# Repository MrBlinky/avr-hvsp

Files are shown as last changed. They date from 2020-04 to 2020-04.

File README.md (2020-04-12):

# avr-hvsp
High voltage serial programmer for AVR Attiny devices

* Easy to make programmer using 12V DC-DC converter with enable and ATMEGA32U4 Beetle board.
* Programs AVR Attiny devices in high voltage mode to recover fuse settings and allow reset pin to be used as GPIO pin.
* Works with Arduino IDE / AVRdude.
* No hassle with Windows driver utilities. Uses built in windows 10 driver or Arduino IDE driver.

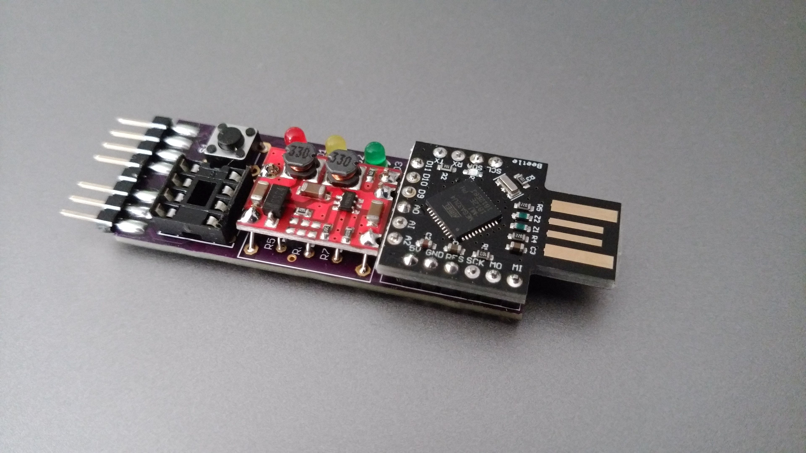
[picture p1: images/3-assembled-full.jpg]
fully assembled image


## Parts

|Qty. | Discription |
| --- | --- |
| 1 | 12V DC-DC converter/booster module with enable |
| 1 | ATMEGA32U4 Beetle board without parts on PCB bottom + headers (No 3.3V pin and no extra GND pins on top row.) |
| 1 | 3 mm Red LED |
| 1 | 3 mm Yellow LED |
| 1 | 3 mm Green LED |
| 5 | 470 Ohm resistor  (1/8 Watt) |
| 2 | 1K resistor (1/8 Watt) |
| 1 | PM48XP P-channel MOSFET SOT23 package (optional)* |
| 1 | 8 pin header (for programming connector) |
| 1 | 2 pin header (for DC-DC converter) |
| 3 | 1 pin header (for DC-DC converter) |
| 1 | 8 pin IC socket |
| 1 | 6x6mm tactile button |
 
*A MOSFET is recommended for a more powerful VCC. However if devices are
 only programmed using the IC socket or in low power circuits (<20mA),
 the MOSFET can be left out. In that case VCC is powered by a GPIO pin
 by shorting jumper J1. When using a MOSFET, Jumper J1 must be left open.

Revision 1.1 PCB can be ordered through [OSH Park](https://oshpark.com/shared_projects/vXxMrB8z)

## Assembly

Assemble parts with low height first (programming header, MOSFET at bottom, resistors IC socket, button, LEDs and modules as last).
Check a parts aligment after soldering the first pin and when it's aligned properly solder remaining pins.

Before soldering the module headers, place headers with long end into main PCB and mount modules on top for easy aligment. Solder one pin of each header at top of module and check if headers are straight then solder remaining pins at top of the modules. Cut excess length of header pins at bottom of the main PCB and then solder them.

## upload programmer firmware

* Open **hvsp.ino** sketch by double clicking or open file with Arduino IDE
* Select **Arduino Leonardo** board from **Tools** menu.
* Select **port** from **Tools** menu.
* Upload sketch

## Programming a device

Insert 8-pin DIP devices in to socket or wire-up device to programming header (check device datasheet for wiring).
Upload a sketch using Arduino IDE or upload a hex file directly using AVRdude.

LED status:
* Red LED on: 12V VPP programming voltage on. Red LED off: Programming voltage off.
* Yellow LED on: 5V VCC on. Yellow LED off: 5V VCC off.
* Green LED on: Both programming and VCC are off. Green LED off: VPP and/or VCC on.

Button control:

Short press (< 500 ms): Toggle VCC on/off.
long press (>= 500 ms): TO DO

### using Arduino IDE

select **Arduino as ISP (ATmega32U4)** as **programmer** from **Tools** menu

### using AVRdude

Use **-carduino** as programmer switch and specify serial port with *-P* switch

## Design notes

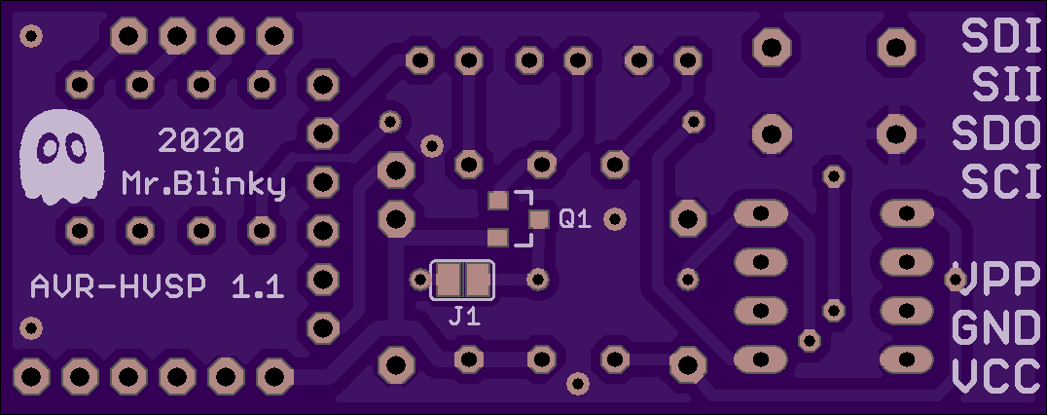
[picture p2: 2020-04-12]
images/rev1.1-bottom.png

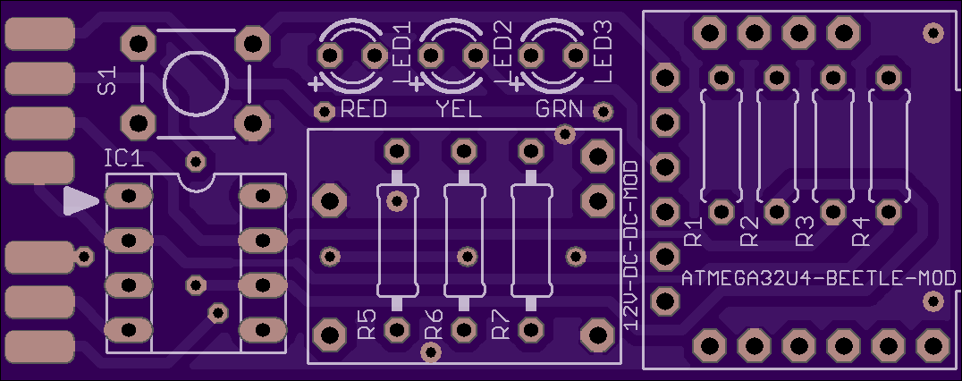
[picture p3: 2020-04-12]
images/rev1.1-top.png

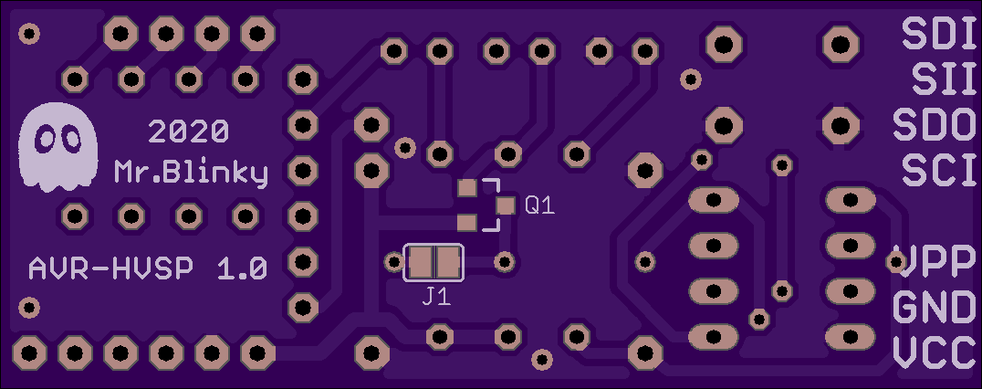
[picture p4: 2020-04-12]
images/rev1.0-bottom.png

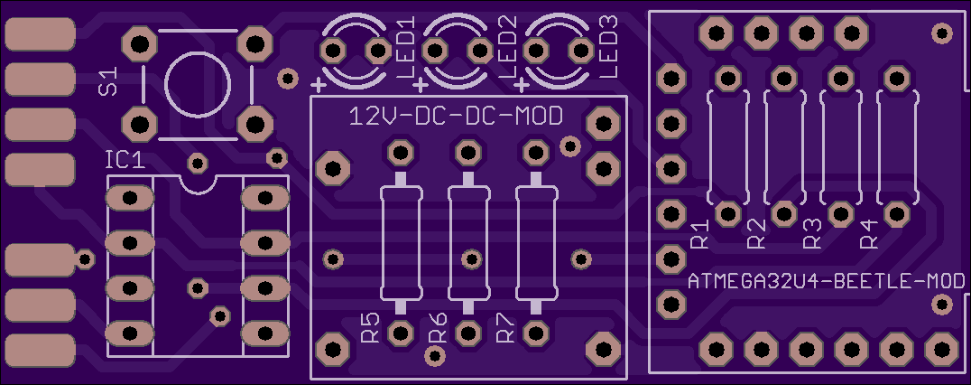
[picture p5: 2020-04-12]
images/rev1.0-top.png

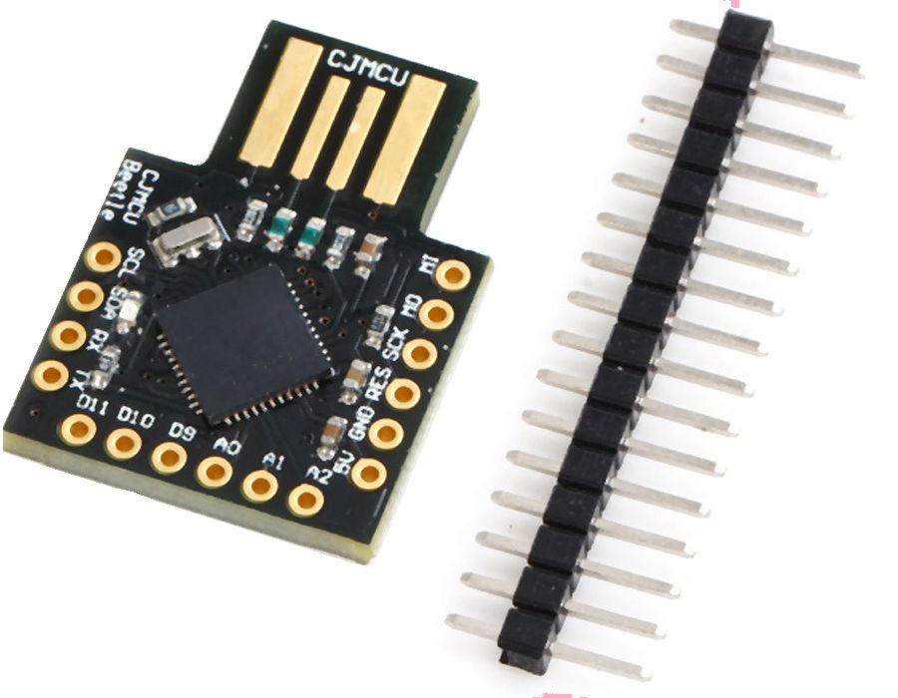
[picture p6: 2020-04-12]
images/beetle-board-without-3v3.jpg

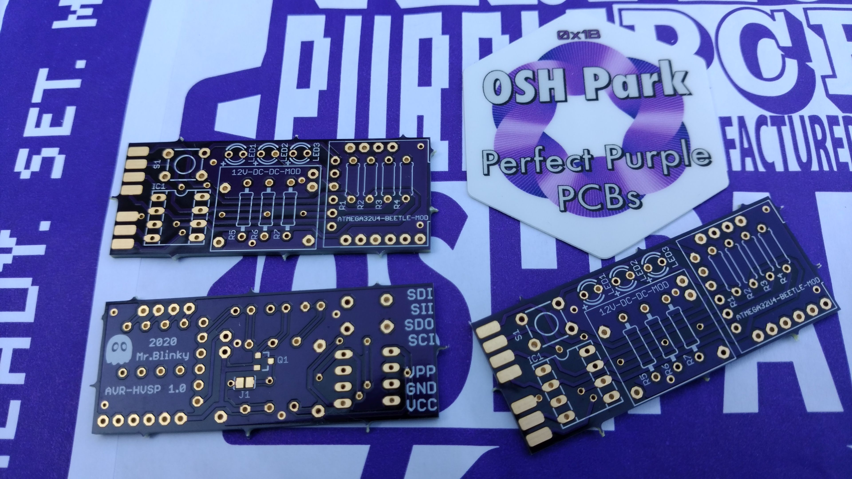
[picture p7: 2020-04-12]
images/1-oshpark-pcb.jpg

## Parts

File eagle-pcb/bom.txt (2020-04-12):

 1x 12V DC-DC converter/booster module with enable
 1x ATMEGA32U4 Beetle board without parts on PCB bottom + headers
    (No 3.3V pin and no extra GND pins on top row.)
 1x 3 mm Red LED
 1x 3 mm Yellow LED
 1x 3 mm Green LED
 5x 470 Ohm resistor  (1/8 Watt)
 2x 1K resistor (1/8 Watt)
 1x PM48XP P-channel MOSFET SOT23 package (optional)*
 1x 8 pin header (for programming connector)
 1x 2 pin header (for DC-DC converter)
 3x 1 pin header (for DC-DC converter)
 1x 8 pin IC socket
 1x 6x6mm tactile button
 
*A MOSFET is recommended for a more powerful VCC. However if devices are only
 programmed using the IC socket or in low power circuits (<20mA), the MOSFET 
 can be left out. In that case VCC is powered by a GPIO pin by shorting
 jumper J1. When using a MOSFET, Jumper J1 must be left open.

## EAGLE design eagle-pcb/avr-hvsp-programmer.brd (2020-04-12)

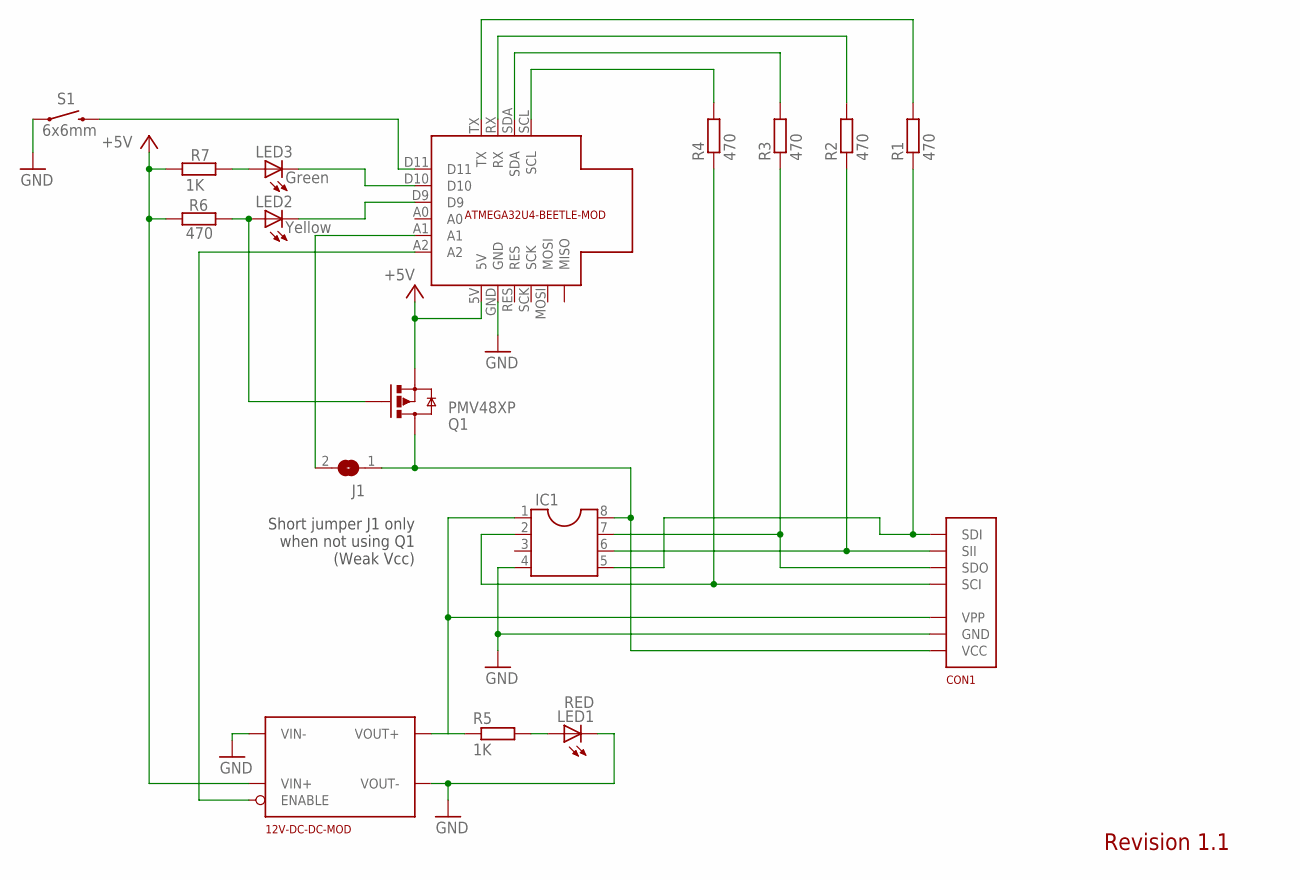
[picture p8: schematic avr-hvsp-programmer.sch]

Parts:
12V-DC-DC-MOD: 12V-DC-DC-CONVERTER-WITH_ENABLE; 12V-DC-DC-CONVERTER-WITH-ENABLE
ATMEGA32U4-BEETLE-MOD: ATMEGA32U4-BEETLE-BOARD
CON1: HVSP-HEADER
IC1: DIL8S; SOCKET-08
J1: SJ
LED1: RED; LED3MM
LED2: Yellow; LED3MM
LED3: Green; LED3MM
Q1: PMV48XP; SOT23-3
R1, R2, R3, R4: 470; 0207/7
R5, R7: 1K; 0207/10
R6: 470; 0207/10
S1: 6x6mm; TACTILE_SWITCH_PTH_6.0MM

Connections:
+5V: 12V-DC-DC-MOD.VIN+, ATMEGA32U4-BEETLE-MOD.5V, Q1.2 (S), R6.1, R7.1
GND: 12V-DC-DC-MOD.VIN-, 12V-DC-DC-MOD.VOUT-, ATMEGA32U4-BEETLE-MOD.GND, CON1.GND, IC1.4, LED1.K (C), S1.1
LED2: ATMEGA32U4-BEETLE-MOD.D9, LED2.K (C)
LED3: ATMEGA32U4-BEETLE-MOD.D10, LED3.K (C)
unnamed: ATMEGA32U4-BEETLE-MOD.TX, R1.2
unnamed: ATMEGA32U4-BEETLE-MOD.RX, R2.2
unnamed: ATMEGA32U4-BEETLE-MOD.SDA, R3.2
unnamed: ATMEGA32U4-BEETLE-MOD.SCL, R4.2
R-LED1: LED1.A, R5.2
R-LED2: LED2.A, Q1.1 (G), R6.2
R-LED3: LED3.A, R7.2
S1: ATMEGA32U4-BEETLE-MOD.D11, S1.3 (2)
SCI: CON1.SCI, IC1.2, R4.1
SDI: CON1.SDI, IC1.5, R1.1
SDO: CON1.SDO, IC1.7, R3.1
SII: CON1.SII, IC1.6, R2.1
VCC: CON1.VCC, IC1.8, J1.1, Q1.3 (D)
VCC_WEAK: ATMEGA32U4-BEETLE-MOD.A1, J1.2
VPP: 12V-DC-DC-MOD.VOUT+, CON1.VPP, IC1.1, R5.1
VPP_ENABLE: 12V-DC-DC-MOD.ENABLE, ATMEGA32U4-BEETLE-MOD.A2

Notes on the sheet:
Short jumper J1 only when not using Q1 (Weak Vcc)
Revision 1.1

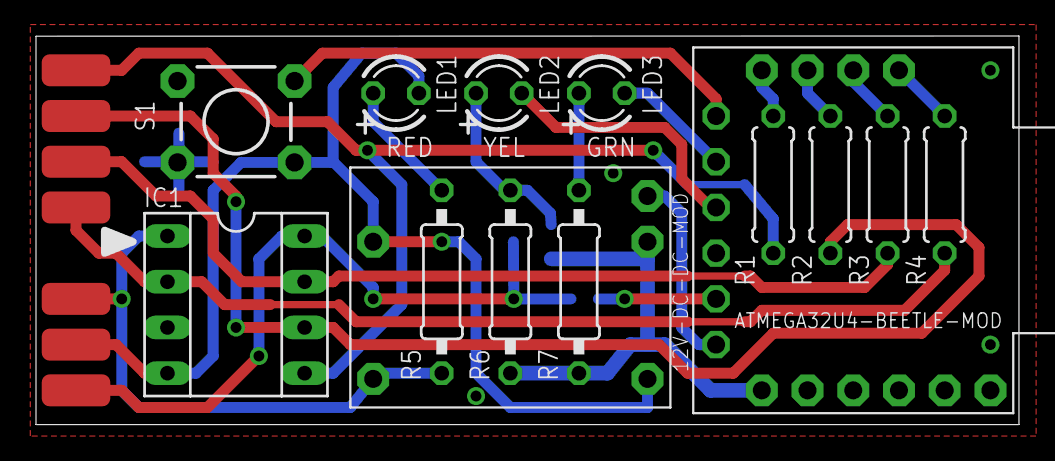
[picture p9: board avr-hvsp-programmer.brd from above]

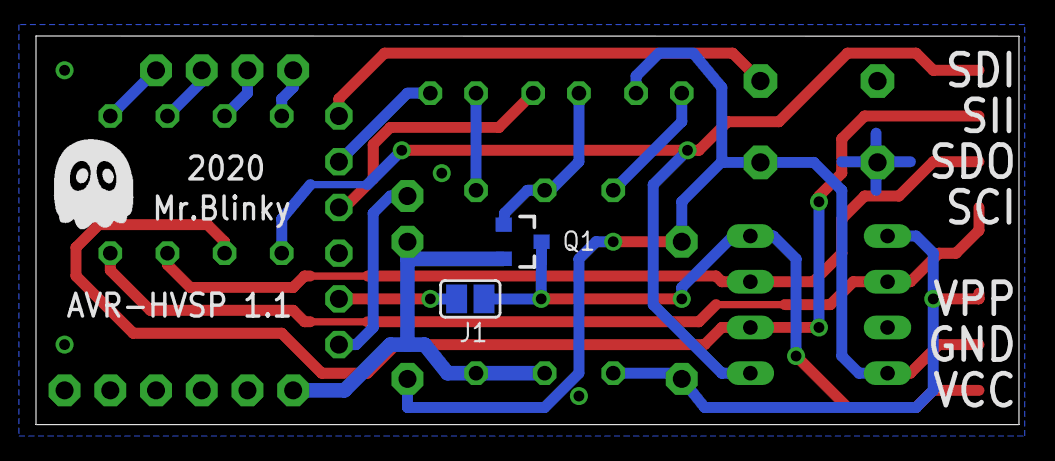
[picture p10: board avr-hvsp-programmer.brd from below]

Board: 2 copper layers, 54.6 x 21.6 mm, 17 parts (2 on the bottom side), 20 nets.

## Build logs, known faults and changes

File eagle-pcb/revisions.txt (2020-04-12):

1.0 First release. Minior issue: DC-DC converter module is 0.1"too wide

1.1 reduced DC-DC converter module width by 0.1"
    adjusted routing due to narrower DC-DC converter module
    increased DC-DC converter module drill size from 0.9mm to 1.0mm
    increased beetle module drill size from 0.9mm to 1.0mm
    changed revision text from 1.0 to 1.1
    
    Schematic changes:    
    changed value red LED resistor R5 to 1K
    changed value yellow LED resistor R6 to 470
    changed value green LED resistor R7 to 1K

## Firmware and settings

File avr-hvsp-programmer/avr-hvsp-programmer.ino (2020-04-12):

/******************************************************************************/
// AVR High Voltage Serial Programmer 1.01 by Mr.Blinky Mar-Apr.2020 CC0 Licence
/******************************************************************************

Atmega32u4 beetle board wiring
------------------------------
 
       SCI __________
       SDO ________  |
       SII ______  | |
       SDI ____  | | |
             __|_|_|_|_______
            |  O O O O       |
BUTTON     _|O               |____
LED_GREEN  _|O        LED         |_BUILTIN_LED
VCC_LED    _|O                    |
           _|O                    |
WEAK_VCC   _|O                ____|
VPP        _|O               |
            |__O_O_O_O_O_O_O_|
        5V ____| |
       GND ______|

connect SCI,SDO,SII and SDI to device with 470 Ohm resistors in series.

connect BUTTON to momentary pushbutton and other end of button to GND

connect cathode(-) of green LED to LED_GREEN pin
connect 330 Ohm resistor to anode(+) of green LED pin
connect other end 330 Ohm resistor to 5V

connect cathode(-) of yellow LED to VCC_LED pin
connect 330 Ohm resistor to anode(+) of yellow LED pin 
connect other end 330 Ohm resistor to 5V

for low power device/circuit:
-----------------------------
Connect WEAK_VCC directly to device VCC pin.

for more demanding circuits:
----------------------------
leave WEAK_VCC unconnected and connect a P-channel MOSFET as following:
Connect MOSFET Source to 5V, Connect MOSFET Drain to device VCC and 
connect MOSFET Gate to anode(+) of yellow LED.

Connect VPP to enable input of 12V DC-DC converter module

connect 1K resistor to 12V
connect other end of 1K resistor to anode(+) of the red LED
connect cathode(-) of the red LED to GND

*******************************************************************************/

// version info
constexpr uint8_t HARDWAREVERSION       = 2;
// 1: for basic prototype made of beetle board, 12V DC-DC converter module and weak vcc
// 2: PCB version with added Vcc LED, Green LED and feature button
//    (P-channel MOSFET for more powerfull VCC is optional)

constexpr uint8_t SOFTWAREVERSION_MAJOR = 1;
constexpr uint8_t SOFTWAREVERSION_MINOR = 1;

// pin configurations (Using direct IO instead of slow DigitalRead/Write and pinMode)

#define HVSP_SCI_BIT    0       // 3/SCL output connected to SCI pin
#define HVSP_SCI_PIN    PIND
#define HVSP_SCI_PORT   PORTD
#define HVSP_SCI_DDR    DDRD

#define HVSP_SDO_BIT    1       // 2/SDA input/output connected to Serial Data Output (SDO) pin
#define HVSP_SDO_PIN    PIND
#define HVSP_SDO_PORT   PORTD
#define HVSP_SDO_DDR    DDRD

#define HVSP_SII_BIT    2       // RX output connect to Serial Instruction Input (SII) pin
#define HVSP_SII_PIN    PIND
#define HVSP_SII_PORT   PORTD
#define HVSP_SII_DDR    DDRD

#define HVSP_SDI_BIT    3       // TX output connected to Serial Data Input (SDI) pin
#define HVSP_SDI_PIN    PIND
#define HVSP_SDI_PORT   PORTD
#define HVSP_SDI_DDR    DDRD
 
#define BUTTON_BIT      7       // D11 Special function button: 
#define BUTTON_PIN      PINB    // short press: toggle VCC state
#define BUTTON_PORT     PORTB   // long press: burn fuse settings and/or embedded hexfile
#define BUTTON_DDR      DDRB

#define GREEN_LED_BIT   6       // D10 active low turns LED on. 
#define GREEN_LED_PIN   PINB    // Status LED to tell both VCC and VPP are disabled
#define GREEN_LED_PORT  PORTB
#define GREEN_LED_DDR   DDRB

#define VCC_LED_BIT     5       // D9 active low turns LED on. 
#define VCC_LED_PIN     PINB    // Status LED to tell VCC_WEAK is enabled.
#define VCC_LED_PORT    PORTB   // when a P-Channel MOSFET is used, it also powers on VCC
#define VCC_LED_DDR     DDRB

#define VCC_BIT         6       // A1 active high turns weak VCC on.
#define VCC_PIN         PINF    // this pin powers VCC directly when no MOSFET is used
#define VCC_PORT        PORTF
#define VCC_DDR         DDRF

#define VPP_BIT         5       // A2 active low turns the 12V DC-DC converter on. 
#define VPP_PIN         PINF    // The RED VPP LED is powered by 12V
#define VPP_PORT        PORTF
#define VPP_DDR         DDRF

#define BUILTIN_LED_BIT  7       // D13 Leonardo/Beetle board built in LED  
#define BUILTIN_LED_PIN  PINC    
#define BUILTIN_LED_PORT PORTC   
#define BUILTIN_LED_DDR  DDRC

// pin configure macros
#define HVSP_SCI_AS_INPUT   (HVSP_SCI_DDR  &= ~(1 << HVSP_SCI_BIT))
#define HVSP_SCI_AS_OUTPUT  (HVSP_SCI_DDR  |=  (1 << HVSP_SCI_BIT))

#define HVSP_SDO_AS_INPUT   (HVSP_SDO_DDR  &= ~(1 << HVSP_SDO_BIT))
#define HVSP_SDO_AS_OUTPUT  (HVSP_SDO_DDR  |=  (1 << HVSP_SDO_BIT))
#define HVSP_SDO_PULLUP_ON  (HVSP_SDO_PORT |=  (1 << HVSP_SDO_BIT))
#define HVSP_SDO_PULLUP_OFF (HVSP_SDO_PORT &= ~(1 << HVSP_SDO_BIT))

#define HVSP_SII_AS_INPUT   (HVSP_SII_DDR  &= ~(1 << HVSP_SII_BIT))
#define HVSP_SII_AS_OUTPUT  (HVSP_SII_DDR  |=  (1 << HVSP_SII_BIT))

#define HVSP_SDI_AS_INPUT   (HVSP_SDI_DDR  &= ~(1 << HVSP_SDI_BIT))
#define HVSP_SDI_AS_OUTPUT  (HVSP_SDI_DDR  |=  (1 << HVSP_SDI_BIT))

#define BUTTON_AS_INPUT     (BUTTON_DDR    &= ~(1 << BUTTON_BIT))
#define BUTTON_PULLUP_ON    (BUTTON_PORT   |=  (1 << BUTTON_BIT))
#define GREEN_LED_AS_OUTPUT (GREEN_LED_DDR |=  (1 << GREEN_LED_BIT))
#define VCC_LED_AS_OUTPUT   (VCC_LED_DDR   |=  (1 << VCC_LED_BIT))

#define VCC_AS_INPUT        (VCC_DDR       &= ~(1 << VCC_BIT))
#define VCC_AS_OUTPUT       (VCC_DDR       |=  (1 << VCC_BIT))
#define VPP_AS_OUTPUT       (VPP_DDR       |= (1 << VPP_BIT))

#define BUILTIN_LED_AS_OUTPUT (BUILTIN_LED_DDR |=  (1 << BUILTIN_LED_BIT))

// pin state macros
#define HVSP_SCI_LOW    (HVSP_SCI_PORT &= ~(1 << HVSP_SCI_BIT))
#define HVSP_SCI_HIGH   (HVSP_SCI_PORT |=  (1 << HVSP_SCI_BIT))
#define HVSP_SDO_LOW    (HVSP_SDO_PORT &= ~(1 << HVSP_SDO_BIT))
#define HVSP_SDO_HIGH   (HVSP_SDO_PORT |=  (1 << HVSP_SDO_BIT))
#define HVSP_SII_LOW    (HVSP_SII_PORT &= ~(1 << HVSP_SII_BIT))
#define HVSP_SII_HIGH   (HVSP_SII_PORT |=  (1 << HVSP_SII_BIT))
#define HVSP_SDI_LOW    (HVSP_SDI_PORT &= ~(1 << HVSP_SDI_BIT)) 
#define HVSP_SDI_HIGH   (HVSP_SDI_PORT |=  (1 << HVSP_SDI_BIT)) 

#define GREEN_LED_OFF   (GREEN_LED_PORT  |=  (1 << GREEN_LED_BIT))
#define GREEN_LED_ON    (GREEN_LED_PORT  &= ~(1 << GREEN_LED_BIT))
#define VCC_LED_OFF     (VCC_LED_PORT    |=  (1 << VCC_LED_BIT))
#define VCC_LED_ON      (VCC_LED_PORT    &= ~(1 << VCC_LED_BIT))
#define VCC_OFF         (VCC_PORT        &= ~(1 << VCC_BIT))
#define VCC_ON          (VCC_PORT        |=  (1 << VCC_BIT))
#define VPP_OFF         (VPP_PORT &= ~(1 << VPP_BIT))
#define VPP_ON          (VPP_PORT |= (1 << VPP_BIT))

#define BUILTIN_LED_OFF (BUILTIN_LED_PORT  &= ~(1 << BUILTIN_LED_BIT))
#define BUILTIN_LED_ON  (BUILTIN_LED_PORT  |=  (1 << BUILTIN_LED_BIT))

// pin input macro
#define HVSP_SDO_STATE  (HVSP_SDO_PIN & (1 << HVSP_SDO_BIT))

// vars
bool progMode;          // programmer state
bool keepVccOn;         // Vcc state after ending programmer mode
uint16_t currAddr;      // current flash/EEPROM word address
uint8_t flashPage;      // flash page of current word address

bool buttonState;
bool buttonStateOld;    
uint16_t oldMillis;
/*******************************************************************************/
// low level hardware functions
/*******************************************************************************/

void vccDown()
{
  VCC_AS_INPUT;
  VCC_OFF;
  VCC_LED_AS_OUTPUT;
  VCC_LED_OFF;
  GREEN_LED_AS_OUTPUT;
  GREEN_LED_ON;
}

void vccUp()
{
  VCC_AS_OUTPUT;
  VCC_ON;
  VCC_LED_AS_OUTPUT;
  VCC_LED_ON;
  GREEN_LED_AS_OUTPUT;
  GREEN_LED_OFF;
}

void HVSP_init()
{
  BUTTON_AS_INPUT;
  BUTTON_PULLUP_ON;
  VPP_AS_OUTPUT;
  VPP_OFF;
  HVSP_disable();
  vccDown();
}

void HVSP_enable()
{
  if (progMode) return; //already in programming mode
  
  if (keepVccOn) // Vcc must be off to successfully enter programming mode
  {
    VPP_ON;      // trigger a device reset to wake possible sleeping devices
    delay(25);
    VPP_OFF;
    delay(25);
    vccDown();
    delay(250);  // wait for Vcc to go down.
  }
  HVSP_SCI_AS_OUTPUT;
  HVSP_SCI_LOW;
  // set Prog_enable pins to '000'
  HVSP_SDO_AS_OUTPUT;
  HVSP_SDO_LOW;
  HVSP_SII_AS_OUTPUT;
  HVSP_SII_LOW;
  HVSP_SDI_AS_OUTPUT;
  HVSP_SDI_LOW;
  // Enter High-voltage Serial programming mode
  vccUp();
  delayMicroseconds(20);
  VPP_ON;
  delayMicroseconds(10);
  // release Prog_enable[2] pin
  HVSP_SDO_AS_INPUT; 
  HVSP_SDO_PULLUP_ON; 
  delayMicroseconds(300);
  progMode = true;
  buttonState = false;
}

void HVSP_disable()
{
  if (progMode) while (!HVSP_SDO_STATE); // wait for pending command to finish
  VPP_OFF;
  HVSP_SDI_AS_INPUT;
  HVSP_SDI_LOW;
  HVSP_SII_AS_INPUT;
  HVSP_SII_LOW;
  HVSP_SCI_AS_INPUT;
  HVSP_SCI_LOW;
  HVSP_SDO_PULLUP_OFF; 
  if (!keepVccOn) vccDown(); // Vcc can be optionally kept on for in circuit development
  progMode = false;
}

void clockPulse()
{
  delayMicroseconds(8); // longer idle time here allowing previously set data to stabelize
  HVSP_SCI_HIGH;        // rising edge clocks data in and out      
  delayMicroseconds(2);
  HVSP_SCI_LOW;
}

uint8_t transfer(uint8_t data, uint8_t cmd)
{
  uint8_t result = 0;
  while (!HVSP_SDO_STATE); // wait for chip ready
  // start bits
  HVSP_SDI_LOW;
  HVSP_SII_LOW;
  clockPulse();
  // 8-bit shifter
  for (uint8_t mask = 128; mask != 0; mask >>= 1)
  {
    HVSP_SDI_LOW;
    if (data & mask) HVSP_SDI_HIGH;
    HVSP_SII_LOW;      
    if (cmd & mask)  HVSP_SII_HIGH;
    if (HVSP_SDO_STATE) result |= mask;
    clockPulse();
  }
  // double stop bits
  HVSP_SDI_LOW;
  HVSP_SII_LOW;
  clockPulse();
  clockPulse();
  return result;
}

/*******************************************************************************/
// HVSP device commands
/*******************************************************************************/

uint8_t readSignatureByte(uint8_t idx)
{
  transfer(0x08, 0x4C);
  transfer(idx, 0x0C);
  transfer(0x00, 0x68);
  return transfer(0x00, 0x6c);
}

void chipErase()
{
  transfer(0x80, 0x4C);
  transfer(0x00, 0x64);
  transfer(0x00, 0x6C);
}

void readFlashMode()
{
  transfer(0x02, 0x4C);
} 

uint8_t readFlashLowByte()
{
  transfer(currAddr, 0x0C);
  transfer(currAddr >> 8, 0x1C);
  transfer(0x00, 0x68);
  return transfer(0x00, 0x6C);
}

uint8_t readFlashHighByte()
{
  transfer(0x00, 0x6C);
  transfer(0x00, 0x78);
  uint8_t result = transfer(0x00, 0x7C);
  transfer(0x00, 0x7C);
  return result;
}

void writeFlashMode()
{
  transfer(0x10, 0x4C);  
}

void loadFlashPageLowByte(uint8_t b) 
{
  flashPage = currAddr >> 8;
  transfer(currAddr & 0xFF, 0x0C);
  transfer(b, 0x2C);
}
  
void loadFlashPageHighByte(uint8_t b) 
{
  transfer(b, 0x3C);
  transfer(0x00, 0x7D);
  transfer(0x00, 0x7C);
}

void writeFlashPage()
{
  transfer(flashPage, 0x1C);
  transfer(0x00, 0x64);
  transfer(0x00, 0x6C);
}

void readEepromMode()
{
  transfer(0x03, 0x4C);
} 

uint8_t readEepromByte()
{
  return readFlashLowByte();
}

void writeEepromMode()
{
  transfer(0x11, 0x4C);
}

// EEPROM can be programmed faster by loading a page and then programming it
 
void loadEepromPage(uint8_t b)
{
  transfer(currAddr, 0x0C);
  transfer(currAddr >> 8, 0x1C);
  transfer(b, 0x2C);
  transfer(0x00, 0x6D);
  transfer(0x00, 0x6C);
}

void writeEepromPage()
{
  transfer(0x00, 0x64);
  transfer(0x00, 0x6C);
}

// program a single byte directly to EEPROM
 
void writeEepromByte(uint8_t b)
{
  transfer(currAddr, 0x0C);
  transfer(currAddr >> 8, 0x1C);
  transfer(b, 0x2C);
  transfer(0x00, 0x6D);
  transfer(0x00, 0x64);
  transfer(0x00, 0x6C);
}

uint8_t readLowFuse()
{
  transfer(0x04, 0x4C);
  transfer(0x00, 0x68);
  return transfer(0x00, 0x6C);
}
void writeLowFuse(uint8_t fuse)
{
   transfer(0x40, 0x4C);
   transfer(fuse, 0x2C);
   transfer(0x00, 0x64);
   transfer(0x00, 0x6C);
}

uint8_t readHighFuse()
{
  transfer(0x04, 0x4C);
  transfer(0x00, 0x7A);
  return transfer(0x00, 0x7E);
}

void writeHighFuse(uint8_t fuse)
{
  transfer(0x40, 0x4C);
  transfer(fuse, 0x2C);
  transfer(0x00, 0x74);
  transfer(0x00, 0x7C);
}

uint8_t readExtFuse()
{
    transfer(0x04, 0x4C);
    transfer(0x00, 0x6A);
    return transfer(0x00, 0x6E);
}

void writeExtFuse(uint8_t fuse)
{
  transfer(0x40, 0x4C);
  transfer(fuse, 0x2C);
  transfer(0x00, 0x66);
  transfer(0x00, 0x6e);
}

uint8_t readLockBits()
{
  transfer(0x04, 0x4C);
  transfer(0x00, 0x78);
  return transfer(0x00, 0x7C);
}

void writeLockBits(uint8_t fuse)
{
  transfer(0x20, 0x4C);
  transfer(fuse, 0x2C);
  transfer(0x00, 0x64);
  transfer(0x00, 0x6c);
}

/******************************************************************************/
// Arduino main functions
/******************************************************************************/

void setup()
{ 
  HVSP_init();
  Serial.begin(115200);
}

void loop()
{
  // serial handled by programmer 
  if (Serial.available() > 0)
  { 
    BUILTIN_LED_ON;
    stk500Programmer();
    BUILTIN_LED_OFF;
  }
  // button feature only available when not in programming mode
  if (!progMode) 
  {
    buttonStateOld = buttonState;
    buttonState = !(BUTTON_PIN & (1 << BUTTON_BIT));
    if ((!buttonStateOld) && buttonState) //just pressed
      oldMillis = (uint16_t) millis();
    if (buttonStateOld && (!buttonState)) //just released
    {
      uint16_t duration;
      uint16_t now = (uint16_t) millis();
      if (now > oldMillis) duration = now - oldMillis;
      else duration = oldMillis - now;
      if (duration > 20) // debounce time
      {
        if (duration < 500) //short press: toggle Vcc
        {
          keepVccOn = !keepVccOn;
          if (keepVccOn) vccUp();
          else vccDown();
        }
        else //long press : Set factory defaults
        {
          //TO DO
        }
      }
    }
  }
}

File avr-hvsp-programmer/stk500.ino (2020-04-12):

/******************************************************************************/
// AVR HVSP stk500v1 lite core  1.01 by Mr.Blinky Mar.2020 CC0 Licence
/*******************************************************************************

based on Atmel application note AN_2525 AVR061: STK500 Communication Protocol,
analyzing USB communications and peeking at AVRdude source.

lite as in limited commands set implemented to support AVRdude thru Arduino IDE
and command line:

* read device ID
* read fuses and lock bits
* chip erase
* read/write flash
* read/write EEPROM (using commandline)

Things learned during developing and debugging this code:

When selecting stk500v1 programmer option with AVRdude using the -cstk500v1 switch
DTR is not set. The Arduino USB core requires DTR to be set otherwise no data is
send to the host. Initally a hack was required but later on I discovered the
Arduino programmer (-carduino switch) basically uses the same protocol and sets
DTR so the hack was no longer required.

TLDR

Use AVRdude with -carduino switch

/******************************************************************************/

// responses
constexpr uint8_t Resp_STK_OK       = 0x10;
constexpr uint8_t Resp_STK_FAILED   = 0x11;
constexpr uint8_t Resp_STK_UNKNOWN  = 0x12;
constexpr uint8_t Resp_STK_NODEVICE = 0x13;
constexpr uint8_t Resp_STK_INSYNC   = 0x14;
constexpr uint8_t Resp_STK_NOSYNC   = 0x15;

// special
constexpr uint8_t Sync_STK_CRC_EOP  = 0x20;

// commands
constexpr uint8_t Cmnd_STK_GET_SYNC         = 0x30;
constexpr uint8_t Cmnd_STK_GET_SIGN_ON      = 0x31;
constexpr uint8_t Cmnd_STK_RESET            = 0x32;
constexpr uint8_t Cmnd_STK_SINGLE_CLOCK     = 0x33;
constexpr uint8_t Cmnd_STK_STORE_PARAMETERS = 0x34;

constexpr uint8_t Cmnd_STK_SET_PARAMETER    = 0x40;
constexpr uint8_t Cmnd_STK_GET_PARAMETER    = 0x41;
constexpr uint8_t Cmnd_STK_SET_DEVICE       = 0x42;
constexpr uint8_t Cmnd_STK_GET_DEVICE       = 0x43;
constexpr uint8_t Cmnd_STK_GET_STATUS       = 0x44;
constexpr uint8_t Cmnd_STK_SET_DEVICE_EXT   = 0x45;

constexpr uint8_t Cmnd_STK_ENTER_PROGMODE   = 0x50;
constexpr uint8_t Cmnd_STK_LEAVE_PROGMODE   = 0x51;
constexpr uint8_t Cmnd_STK_CHIP_ERASE       = 0x52;
constexpr uint8_t Cmnd_STK_CHECK_AUTOINC    = 0x53;
constexpr uint8_t Cmnd_STK_CHECK_DEVICE     = 0x54;
constexpr uint8_t Cmnd_STK_LOAD_ADDRESS     = 0x55;
constexpr uint8_t Cmnd_STK_UNIVERSAL        = 0x56;

constexpr uint8_t Cmnd_STK_PROG_FLASH       = 0x60;
constexpr uint8_t Cmnd_STK_PROG_DATA        = 0x61;
constexpr uint8_t Cmnd_STK_PROG_FUSE        = 0x62;
constexpr uint8_t Cmnd_STK_PROG_LOCK        = 0x63;
constexpr uint8_t Cmnd_STK_PROG_PAGE        = 0x64;
constexpr uint8_t Cmnd_STK_PROG_FUSE_EXT    = 0x65;

constexpr uint8_t Cmnd_STK_READ_FLASH       = 0x70;
constexpr uint8_t Cmnd_STK_READ_DATA        = 0x71;
constexpr uint8_t Cmnd_STK_READ_FUSE        = 0x72;
constexpr uint8_t Cmnd_STK_READ_LOCK        = 0x73;
constexpr uint8_t Cmnd_STK_READ_PAGE        = 0x74;
constexpr uint8_t Cmnd_STK_READ_SIGN        = 0x75;
constexpr uint8_t Cmnd_STK_READ_OSCCAL      = 0x76;
constexpr uint8_t Cmnd_STK_READ_FUSE_EXT    = 0x77;
constexpr uint8_t Cmnd_STK_READ_OSCCAL_EXT  = 0x78;

// parameters
constexpr uint8_t Parm_STK_HW_VER           = 0x80;
constexpr uint8_t Parm_STK_SW_MAJOR         = 0x81;
constexpr uint8_t Parm_STK_SW_MINOR         = 0x82;

// parameter structure
struct Params
{
  uint8_t devicecode;
  uint8_t revision;
  uint8_t progtype;
  uint8_t parmode;
  uint8_t polling;
  uint8_t selftimed;
  uint8_t lockbytes;
  uint8_t fusebytes;
  uint8_t flashpollval1;
  uint8_t flashpollval2;
  uint8_t eeprompollval1;
  uint8_t eeprompollval2;
  uint8_t pagesizehigh;     // 16-bit big endian flashmemory programming pagesize in bytes
  uint8_t pagesizelow;
  uint8_t eepromsizehigh;   // 16-bit big endian eeprom size in bytes
  uint8_t eepromsizelow;
  uint8_t flashsize4;       // 32-bit big endian flash size in bytes
  uint8_t flashsize3;
  uint8_t flashsize2;
  uint8_t flashsize1;
};

Params    params;
uint8_t   eepromPageSize;

// low level serial functions

uint8_t readByte()
{
  while (Serial.available() <= 0);
  return Serial.read();
}

void writeByte(uint8_t b)
{
  Serial.write(b);
}

// STK functions

void writeNoSync()
{
  writeByte(Resp_STK_NOSYNC);
}

void writeInSync()
{
  writeByte(Resp_STK_INSYNC);
}

void writeOK()
{
  writeByte(Resp_STK_OK);
}

bool endOfPacket()
{
  if (readByte() == Sync_STK_CRC_EOP) return true;

  writeNoSync();
  return false;
}

void endOfCommand()
{
  if (endOfPacket())
  {
    writeInSync();
    writeOK();
  }
}

void getParameter()
{
  uint8_t b = readByte();
  if      (b == Parm_STK_HW_VER)   b = HARDWAREVERSION;
  else if (b == Parm_STK_SW_MAJOR) b = SOFTWAREVERSION_MAJOR;
  else if (b == Parm_STK_SW_MINOR) b = SOFTWAREVERSION_MINOR;
  else b = 0;
  if (endOfPacket())
  {
    writeInSync();
    writeByte(b);
    writeOK();
  }
}

void setDeviceParams()
{
  for(uint8_t i = 0; i < sizeof(params); i++)
    *(uint8_t*)(&params + i) = readByte();
  endOfCommand();
}
void setDeviceExtParams()
{
  uint8_t len = readByte();
  eepromPageSize = readByte(); // only required ext device param
  for(uint8_t i = 2; i < len; i++) readByte(); // ignore all others
  endOfCommand();
}

// AVRdude uses universal (SPI)command rather than the STK commands for:
// read signature, read/write fuses, chip erase

void universalCommand()
{
  uint16_t cmd = (readByte() << 8) | readByte();
  uint8_t idx = readByte();
  uint8_t data =readByte();
  if (endOfPacket())
  {
    writeInSync();
    switch (cmd)
    {
      case 0x3000:                      // prefered by stk500v1 programmer
        data = readSignatureByte(idx);
        break;
      case 0x5000:
      data = readLowFuse();
        break;
      case 0x5008:
      data = readExtFuse();
        break;
      case 0x5800:
        data = readLockBits();
        break;
      case 0x5808:
        data = readHighFuse();
        break;
      case 0xAC80:
        chipErase();
        break;
      case 0xACA0:
        writeLowFuse(data);
        break;
      case 0xACA4:
        writeExtFuse(data);
        break;
      case 0xACA8:
        writeHighFuse(data);
        break;
      case 0xACE0:
        writeLockBits(data);
        break;
    }
    writeByte(data);
    writeOK();
  }
}

void readPage()
{
  int16_t len = (readByte() << 8) | readByte();
  uint8_t memType = readByte();
  if (endOfPacket())
  {
    writeInSync();
    if (memType == 'E')
    {
      readEepromMode();
      currAddr <<= 1;
      while (len--)
      {
        writeByte(readEepromByte());
        ++currAddr;
      }
      currAddr >>= 1;
    }
    else
    {
      readFlashMode();
      while (len--)
      {
        writeByte(readFlashLowByte());
        if (len)
        {
          writeByte(readFlashHighByte());
          --len;
        }
        ++currAddr;
      }
    }
    writeOK();
  }
}
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

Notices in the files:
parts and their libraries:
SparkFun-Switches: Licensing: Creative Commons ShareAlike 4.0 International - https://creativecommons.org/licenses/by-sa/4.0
